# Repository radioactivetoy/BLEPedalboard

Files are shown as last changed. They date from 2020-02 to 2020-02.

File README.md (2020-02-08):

# BLEPedalboard
Bluethooth BLE Pedalboard

This pedalboard is targeted to work Yamaha ThrII series amps, but can be adapted to work with any Midi Bluetooth device.

The pedalboard has two modes that are be switched pushing the M footswitch.
Mode 0: Changes between the 5 stored pressets
Mode 1: Turns on/ff each of the 5 effects (Compressor, Nosise Gate, Modulation, Echo, Reverb)

The pedalboard needs to talk with the Yamaha THR android App, this is an amp limitation.

* Materials:
  * ESP32 WROOM32 Board https://es.aliexpress.com/item/32348063163.html?spm=a2g0s.9042311.0.0.7f8363c0Pb0CUG
  * 6 SPST Footswitches https://es.aliexpress.com/item/32864722159.html?spm=a2g0s.9042311.0.0.7f8363c0Pb0CUG4
  * 0,96 Inches OLED Display https://es.aliexpress.com/item/32896971385.html?spm=a2g0s.9042311.0.0.7f8363c0Pb0CUG
  * Wires (I used dupond wires)
  * 3D printer for the housing

* Connections:
  * Screen:
    * GPIO 21 (D21)- DISPLAY SDA
    * GPIO 22 (D22)- DISPLAU SCK
    * 3V3 		       DIPLAY  VDD
    * GND			       DISPLAY GND (common grond with all buttons)

  * Buttons:
    * GPIO 13 (D13)		   Button 1
    * GPIO 25	(D25)	    Button 2
    * GPIO 26	(D26)	    Button 3
    * GPIO 27	(D27)	    Button 4
    * GPIO 32	(D32)	    Button 5
    * GPIO 33 (D33)     Button M
    * One side of each button goes to GPIOs and the other one to ground. Wire one common ground, the screen GND and all buttons, to ESP32 GND.

Load the program on arduino IDE. You need to add the needed libraries (adafruit screen libraries and ESP32 https://github.com/espressif/arduino-esp32)

Compile and upload the program, you need keep the Boot button pushed on the ESP32 until it begins uploading.

Once it is uploaded it will wait to the bluetooth connection to be opened, once it is connected, connect the app to the Amp too and you are good to rock. You can power it with a small powerbank.

Pnce you have all tested, use a 3Dprinter to print the housing ( Side has to be printed 2 times).

WIRING:
Wiring
Preset Mode:
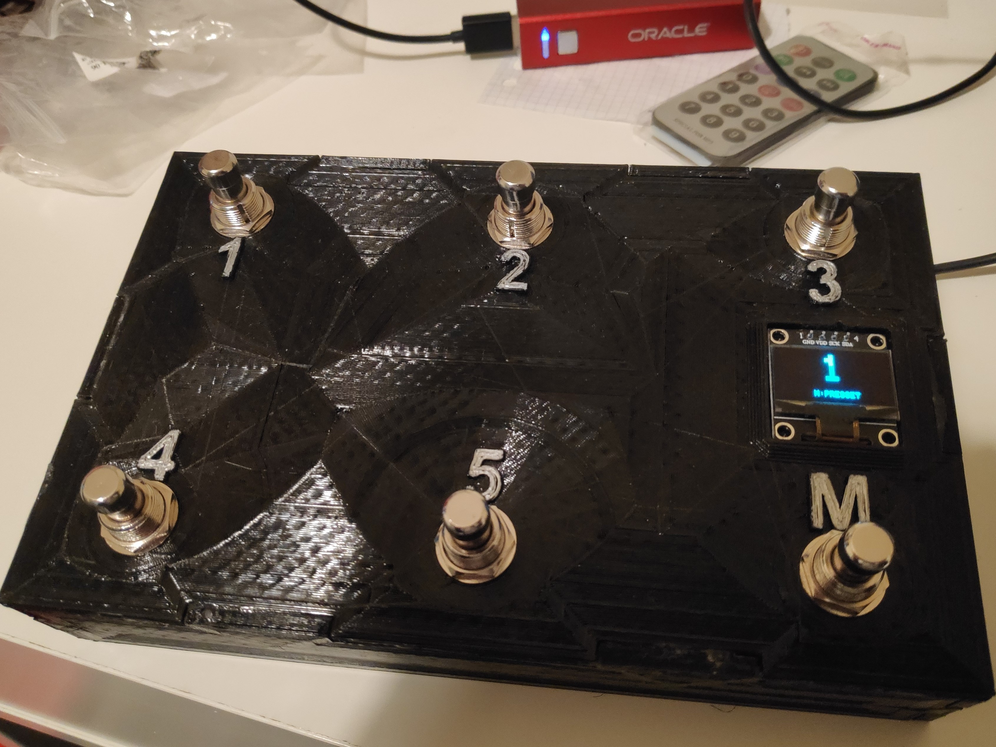
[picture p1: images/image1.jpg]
Pedalboard Presset Mode

Effect Mode:
Peadlboard Effect Mode

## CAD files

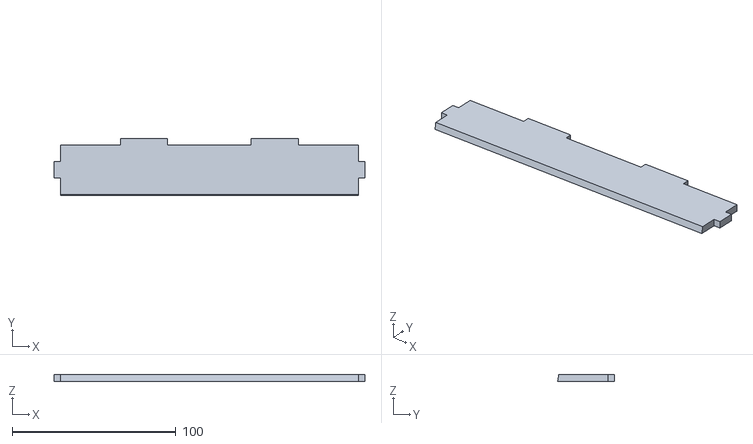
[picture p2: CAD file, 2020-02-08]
Pedalboard_down.stl
190.0 x 34.7 x 4.00

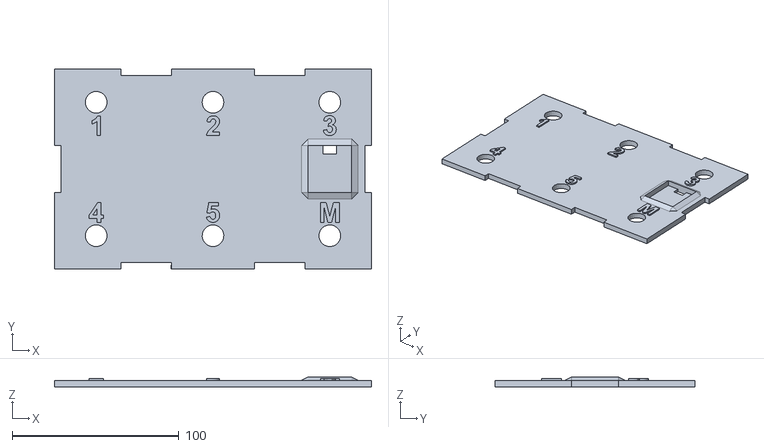
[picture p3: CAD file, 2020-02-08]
Pedalboard_Front.stl
190.0 x 120.0 x 6.00

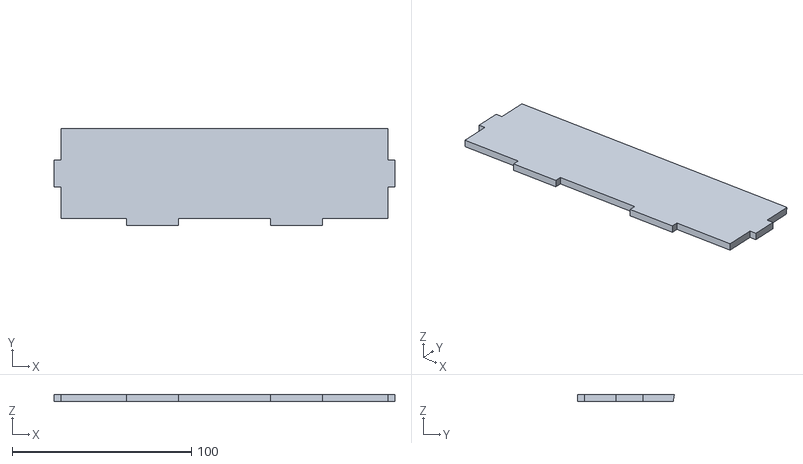
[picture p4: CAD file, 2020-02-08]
Pedalboard_up.stl
190.0 x 54.0 x 4.00

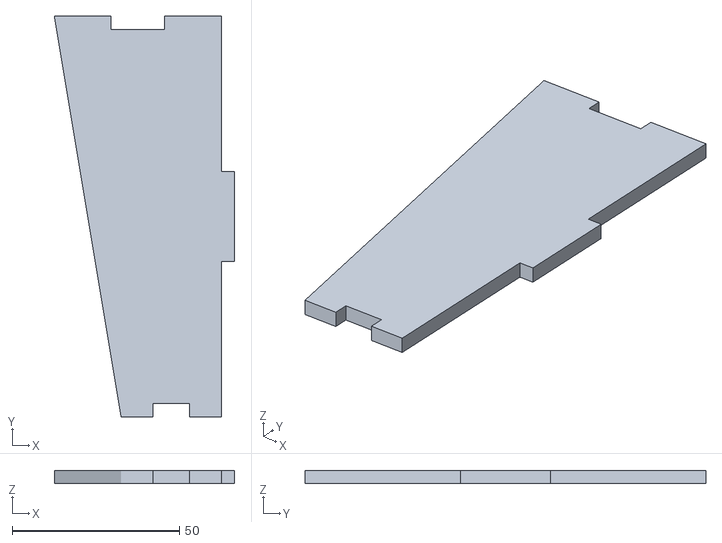
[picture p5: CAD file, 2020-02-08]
Pedalboard_side.stl
54.0 x 120.0 x 4.00

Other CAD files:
Pedalera5.skp

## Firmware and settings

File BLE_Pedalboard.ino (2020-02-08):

/*
    BLE_MIDI Example by neilbags
    https://github.com/neilbags/arduino-esp32-BLE-MIDI

    Based on BLE_notify example by Evandro Copercini.
    Creates a BLE MIDI service and characteristic.
    Once a client subscibes, send a MIDI message every 2 seconds
*/
// Bluetooth Includes
#include <BLEDevice.h>
#include <BLEUtils.h>
#include <BLEServer.h>
#include <BLE2902.h>

#include <SPI.h>
#include <Wire.h>
#include <Adafruit_GFX.h>  // Check if needed
#include <Adafruit_SSD1306.h>


#define SCREEN_WIDTH 128 // OLED display width, in pixels
#define SCREEN_HEIGHT 64 // OLED display height, in pixels

#define SERVICE_UUID        "03b80e5a-ede8-4b33-a751-6ce34ec4c700"
#define CHARACTERISTIC_UUID "7772e5db-3868-4112-a1a9-f2669d106bf3"

// Declaration for an SSD1306 display connected to I2C (SDA, SCL pins)
Adafruit_SSD1306 display(SCREEN_WIDTH, SCREEN_HEIGHT, &Wire, -1);

// Bluetooth Setup
BLECharacteristic *pCharacteristic;
bool deviceConnected = false;
bool connected = true;

// GPIO for each button

int button_0 = 13;
int button_1 = 25;
int button_2 = 26;
int button_3 = 27;
int button_4 = 32;
int button_m = 33;

int buttondelay = 1200; // Button delay time to prevent flapping - Setting this lower than 1,2s crashes the thr android app

// CC Numner for modes 0 (preset) and 1 (effect)
uint8_t ccnumber[5][2] = {{0x14, 0x19}, {0x15, 0x1A}, {0x16, 0x1B}, {0x17, 0x1C}, {0x18, 0x1D}};
bool opmode = 0; // current operation modes 0 (preset) and 1 (effect)
volatile int pushedbutton = 0; // Pushed Button
volatile bool sendmidi = false;
volatile bool pushed = false;
int currpreset = 1;

uint8_t midiPacket[] = {
  0x80,  // header
  0x80,  // timestamp, not implemented
  0xb0,  // Continuous controller Chanel 1
  0x14,  // #20
  0x7F   // 7F press 0 Release
};

class MyServerCallbacks: public BLEServerCallbacks {
    void onConnect(BLEServer* pServer) {
      deviceConnected = true;
    };

    void onDisconnect(BLEServer* pServer) {
      deviceConnected = false;
    }
};

void setup() {
  Serial.begin(115200);

  // Bluetooth Setup
  BLEDevice::init("BLE Floorboard");

  // Create the BLE Server
  BLEServer *pServer = BLEDevice::createServer();
  pServer->setCallbacks(new MyServerCallbacks());
  // Create the BLE Service
  BLEService *pService = pServer->createService(BLEUUID(SERVICE_UUID));
  // Create a BLE Characteristic
  pCharacteristic = pService->createCharacteristic(
                      BLEUUID(CHARACTERISTIC_UUID),
                      BLECharacteristic::PROPERTY_READ   |
                      BLECharacteristic::PROPERTY_WRITE  |
                      BLECharacteristic::PROPERTY_NOTIFY |
                      BLECharacteristic::PROPERTY_WRITE_NR
                    );
  // https://www.bluetooth.com/specifications/gatt/viewer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
  // Create a BLE Descriptor
  pCharacteristic->addDescriptor(new BLE2902());
  // Start the service
  pService->start();
  // Start advertising
  BLEAdvertising *pAdvertising = pServer->getAdvertising();
  pAdvertising->addServiceUUID(pService->getUUID());
  pAdvertising->start();

  // Display Setup
  if (!display.begin(SSD1306_SWITCHCAPVCC, 0x3C)) { // Address 0x3D for 128x64
    Serial.println(F("SSD1306 allocation failed"));
    for (;;);
  }
  display.clearDisplay();

  // GPIO Setup
  pinMode(button_0, INPUT_PULLUP);
  pinMode(button_1, INPUT_PULLUP);
  pinMode(button_2, INPUT_PULLUP);
  pinMode(button_3, INPUT_PULLUP);
  pinMode(button_4, INPUT_PULLUP);
  pinMode(button_m, INPUT_PULLUP);
  // Interrputs on button push  attachInterrupt(digitalPinToInterrupt(button_0), buttonevent_0, FALLING);
  attachInterrupt(digitalPinToInterrupt(button_0), buttonevent_0, FALLING);
  attachInterrupt(digitalPinToInterrupt(button_1), buttonevent_1, FALLING);
  attachInterrupt(digitalPinToInterrupt(button_2), buttonevent_2, FALLING);
  attachInterrupt(digitalPinToInterrupt(button_3), buttonevent_3, FALLING);
  attachInterrupt(digitalPinToInterrupt(button_4), buttonevent_4, FALLING);
  attachInterrupt(digitalPinToInterrupt(button_m), buttonevent_m, FALLING);
}

void loop() {
  if (deviceConnected) {
    if (!connected) { //First screen update / uknown patch
      connected = true;
      display.clearDisplay();
      display.setCursor(50, 5);
      display.setTextSize(5);
      display.setTextColor(WHITE);
      // Display static text
      display.println("?");
      display.setCursor(40, 55);
      display.setTextSize(1);
      display.setTextColor(WHITE);
      display.println("M:PRESSET");
      display.display();
    }
    if (pushed) {
      pushed = false;
      if (pushedbutton == 5) {
        opmode = !opmode;
      } else {
        if (opmode==false) currpreset = pushedbutton + 1;
      }
      if (opmode ==  false) {
        display.clearDisplay();
        display.setCursor(50, 5);
        display.setTextSize(5);
        display.setTextColor(WHITE);
        display.println(currpreset);
        display.setCursor(40, 55);
        display.setTextSize(1);
        display.setTextColor(WHITE);
        display.println("M:PRESSET");
        display.display();
      } else {
        display.clearDisplay();
        display.setTextSize(1);
        display.setCursor(0, 5);
        display.println("1-CMP");
        display.setCursor(1, 15);
        display.println("2-NG");
        display.setCursor(1, 25);
        display.println("3-MOD");
        display.setCursor(1, 35);
        display.println("4-DLY");
        display.setCursor(1, 45);
        display.println("5-REV");
        display.setCursor(50, 5);
        display.setTextSize(5);
        display.setTextColor(WHITE);
        display.println(currpreset);
        display.setCursor(40, 55);
        display.setTextSize(1);
        display.setTextColor(WHITE);
        display.println("M:EFFECT");
        display.display();
      }
      if (sendmidi) {
        // Send Push
        midiPacket[3] = ccnumber[pushedbutton][opmode]; // test code, change to pushedbutton
        midiPacket[4] = 0x7F; // CC Max Value
        pCharacteristic->setValue(midiPacket, 5); // packet, length in bytes
        pCharacteristic->notify();


        // Send release - Not needed on the thr
        //midiPacket[4]=0x00; // CC Min Value (Release)
        //pCharacteristic->setValue(midiPacket, 5); // packet, length in bytes
        //pCharacteristic->notify();

        sendmidi = false;
      }

      delay(buttondelay);
      pushed = false;//
    }
  } else if (connected) { // Update the display only when Connectio status is changed
    connected = false;
    display.clearDisplay();
    display.setCursor(1, 1);
    display.setTextSize(1);
    display.setTextColor(WHITE);
    display.println("RadioactiveToy");
    display.println("BLE Pedalboard");
    display.println("Bluetooth not connected");
    display.display();
  }
}


void  buttonevent_0() {
  sendmidi = true;
  pushedbutton = 0;
  pushed = true;
}

void  buttonevent_1() {
  sendmidi = true;
  pushedbutton = 1;
  pushed = true;
}

void  buttonevent_2() {
  sendmidi = true;
  pushedbutton = 2;
  pushed = true;
}

void  buttonevent_3() {
  sendmidi = true;
  pushedbutton = 3;
  pushed = true;
}

void buttonevent_4() {
  sendmidi = true;
  pushedbutton = 4;
  pushed = true;
}

void  buttonevent_m() {
  pushedbutton = 5;
  pushed = true;
}

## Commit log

2020-02-08 Added STL Files for 3 printing
    [Pedalboard_Front.stl, Pedalboard_down.stl, Pedalboard_side.stl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]
2020-02-08 Added sketchup file
    [Pedalera5.skp]
